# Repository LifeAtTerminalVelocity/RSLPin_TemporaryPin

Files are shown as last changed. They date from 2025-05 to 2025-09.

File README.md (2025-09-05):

# RSLPin TemporaryPin
This project is a Parachute Reserve packing temporary pin, being made out of an RSL Pin

The idea for this project started at the Parachute Industry Association (PIA) Symposium of 2025 held in Daytona Beach, Florida, USA.

A common problem that parachute riggers have is that the temporary pins that they employ to close the reserve pack tray are:
1) Expensive (relative to their expected lifetime).
2) Soft, easy to deform.
3) Deformations turn into nicks or gouges on the pin that damage the reserve closing loop.
4) Have to be replaced frequently.

The idea is to take a straight RSL Pin (Currently being made by CWH in Italy and sold world wide through their regional subsidiaries), encase said pin in a 3d printed plastic form to lend it rigidity and structure, and then having that encased in Type 3 webbing as a means to handle it and track it.

This repository will host the STL files needed to print the pin retention and rigidity plastic. This will also serve as to document the process of edits to this project. Keep in mind that in order to have greater strength and rigidity I have printed these using ASA and 100% infill. I have tried making versions that use lesser infill and they tend to fail after some time in the center stud that carries the load of the pin eye.

The latest STL files:

  v10.x - <a href="https://github.com/LifeAtTerminalVelocity/RSLPin_TemporaryPin/blob/main/STL/RSL_Pin_v10.2_Long.stl">Latest 10.x STL Long</a>

  v10.x - <a href="https://github.com/LifeAtTerminalVelocity/RSLPin_TemporaryPin/blob/main/STL/RSL_Pin_v10.2_Regular.stl">Latest 10.x STL Regular</a>
  
  v10.x - <a href="https://github.com/LifeAtTerminalVelocity/RSLPin_TemporaryPin/blob/main/STL/RSL_Pin_v10.2_Short.stl">Latest 10.x STL Short</a>

  Straight Pin Short v2.1 <a href="https://github.com/LifeAtTerminalVelocity/RSLPin_TemporaryPin/blob/main/STL/StraightPin_v2.1_Short.stl"> Latest Stright Pin 2.x Short STL</a>

The latest 3MF files:
  
  v10.x - <a href="https://github.com/LifeAtTerminalVelocity/RSLPin_TemporaryPin/blob/main/3MF/RSL_Pin_v10.2_Long.3mf">Latest 10.x 3MF Long</a>

  v10.x - <a href="https://github.com/LifeAtTerminalVelocity/RSLPin_TemporaryPin/blob/main/3MF/RSL_Pin_v10.2_Regular.3mf">Latest 10.x 3MF Regular</a>

  v10.x - <a href="https://github.com/LifeAtTerminalVelocity/RSLPin_TemporaryPin/blob/main/3MF/RSL_Pin_v10.2_Short.3mf">Latest 10.x 3MF Short</a>

The history of the project can be read here - <a href="https://github.com/LifeAtTerminalVelocity/RSLPin_TemporaryPin/blob/main/History.md"> History.md </a>

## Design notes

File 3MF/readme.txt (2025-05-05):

These are 3MF files. I have a Bambu printer and the Bambu Studio default file type is 3MF.

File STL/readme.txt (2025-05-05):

These are STL files. If you are new to 3d printing this is the kind of file you need to add into your slicer to then generate a print.

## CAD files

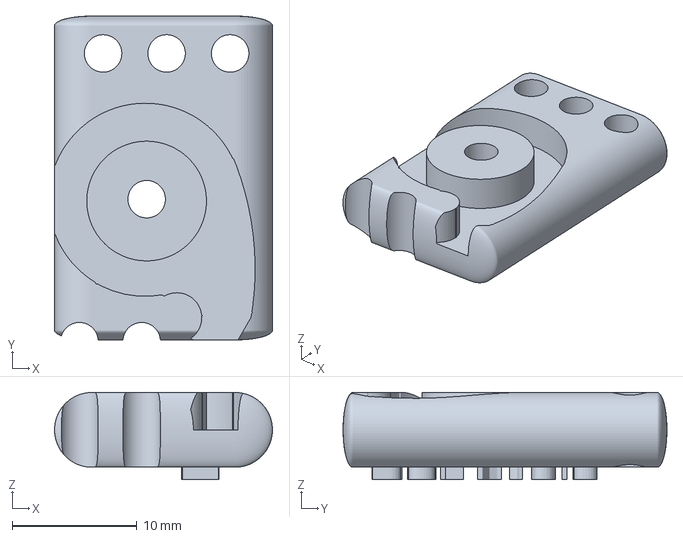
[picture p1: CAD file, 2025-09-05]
3MF/RSL_Pin_v10.2_Short.3mf
17.5 x 26.0 x 6.99 mm

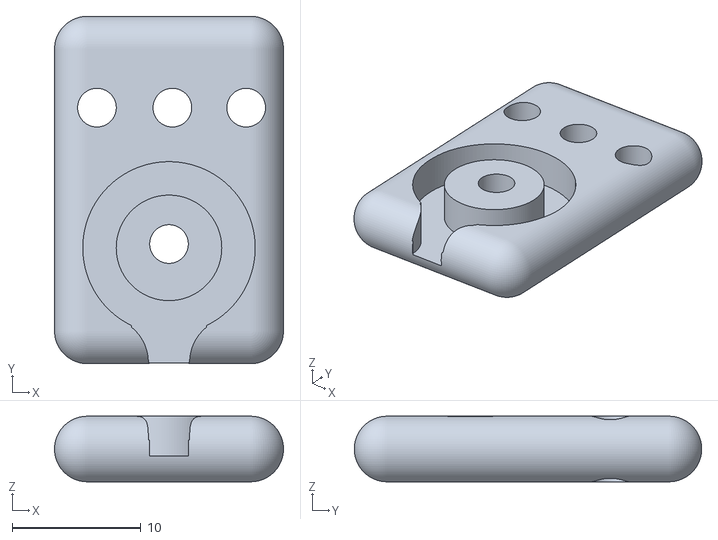
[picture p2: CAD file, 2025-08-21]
STL/StraightPin_v2.1_Short.stl
17.8 x 27.0 x 5.10

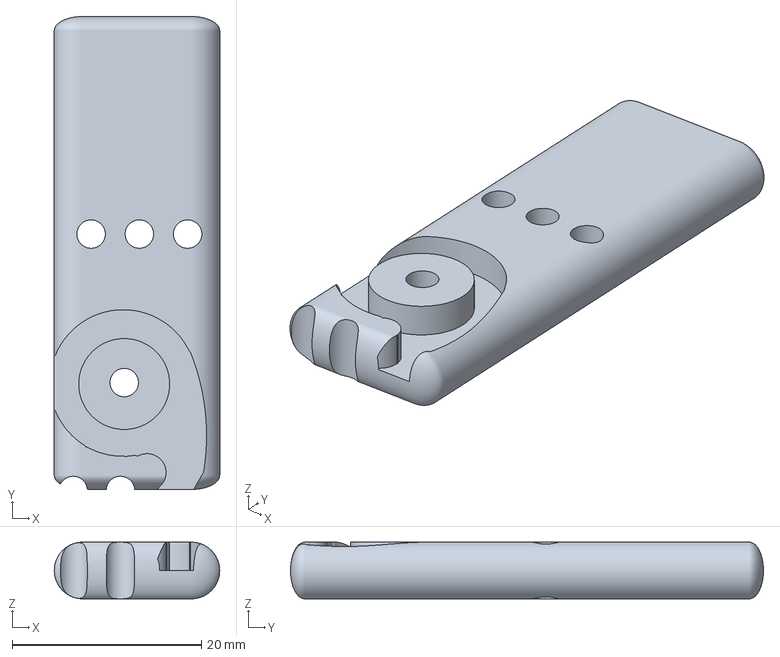
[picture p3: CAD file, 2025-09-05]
3MF/RSL_Pin_v10.2_Regular.3mf
17.5 x 50.0 x 6.00 mm

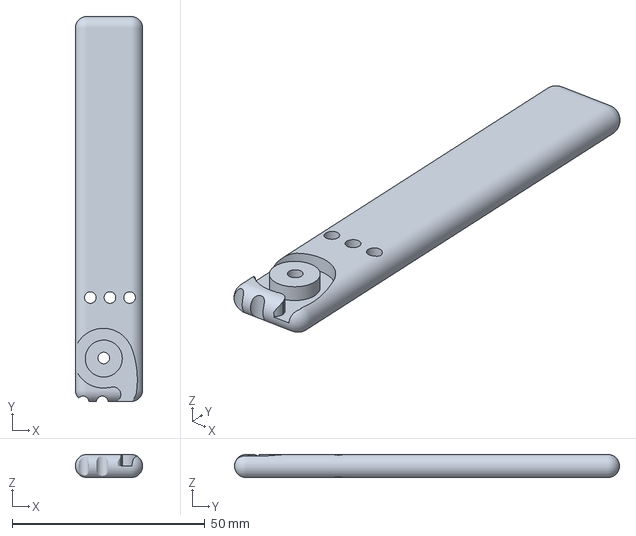
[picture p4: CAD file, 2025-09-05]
3MF/RSL_Pin_v10.2_Long.3mf
17.5 x 100.0 x 6.00 mm

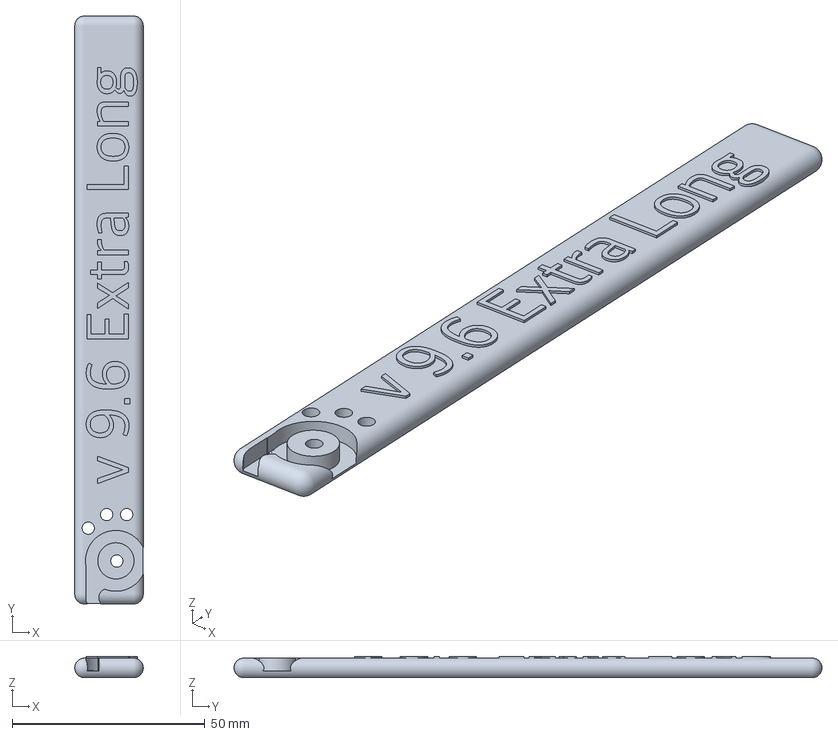
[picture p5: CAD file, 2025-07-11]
3MF/RSL Pin Holder - v9.6 ExtraLong.3mf
17.8 x 152.4 x 5.54 mm

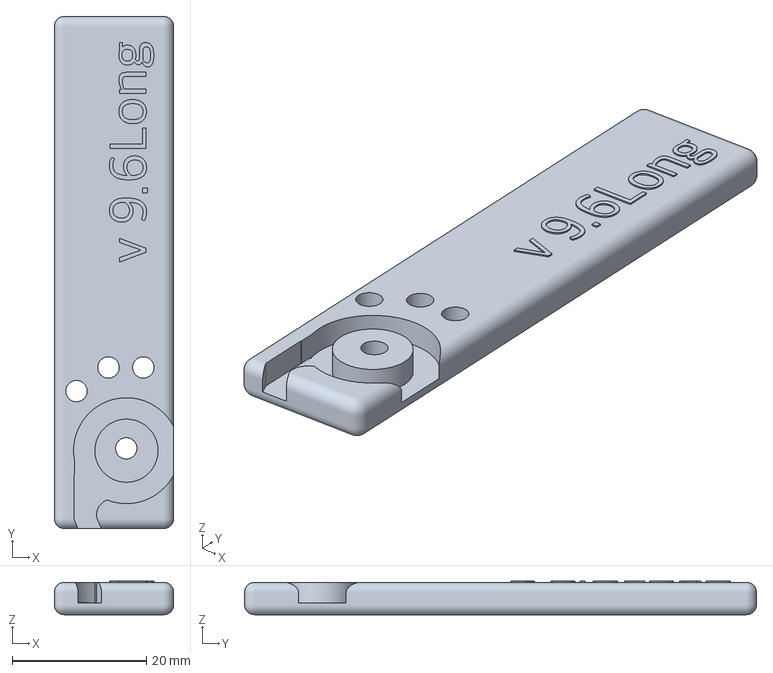
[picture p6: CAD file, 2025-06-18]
3MF/RSL Pin Holder - v9.6 Long.3mf
17.8 x 76.2 x 4.99 mm

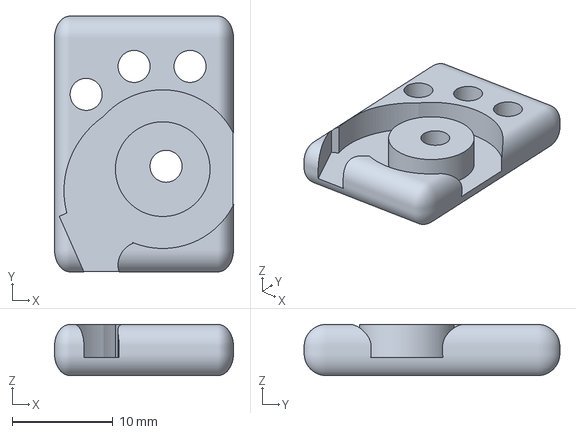
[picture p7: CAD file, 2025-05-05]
3MF/RSL Pin Holder - v9.5.3mf
17.8 x 25.4 x 5.08 mm

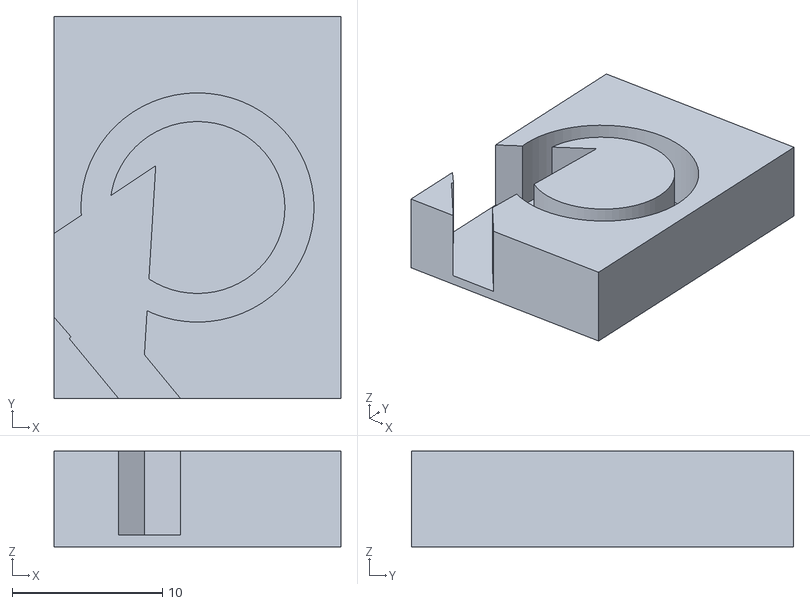
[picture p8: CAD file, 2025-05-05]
STL/RSL Pin Holder.stl
19.1 x 25.4 x 6.35

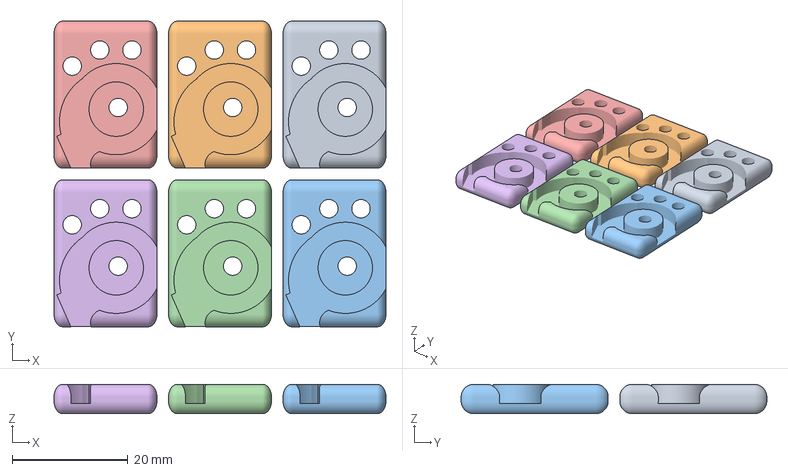
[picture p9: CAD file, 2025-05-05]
3MF/RSL Pin Holder - v9.1mf.3mf
57.3 x 52.8 x 5.08 mm
RSL Pin Holder - v9.1.stl x 6

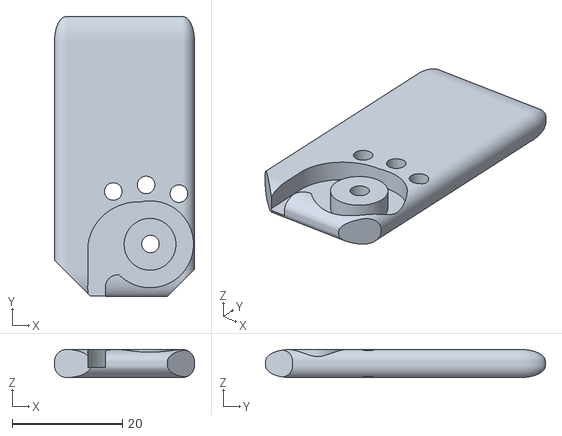
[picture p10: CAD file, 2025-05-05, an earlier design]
STL/RSL Pin Holder - v7.1.stl
25.4 x 50.8 x 5.08

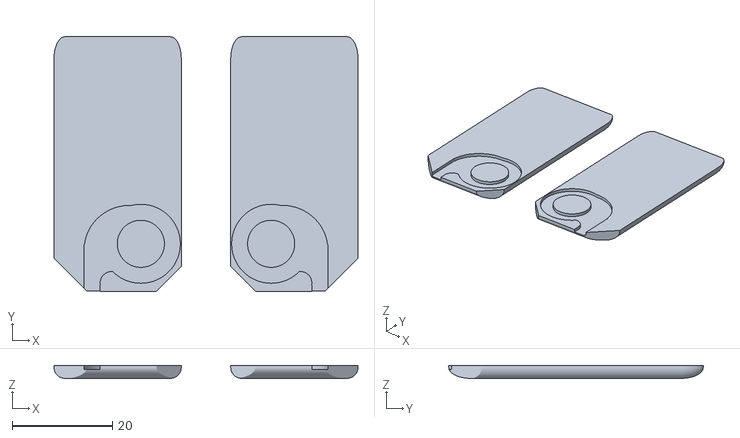
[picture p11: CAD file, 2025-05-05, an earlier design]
STL/RSL Pin Holder - v8.stl
60.7 x 50.8 x 2.54

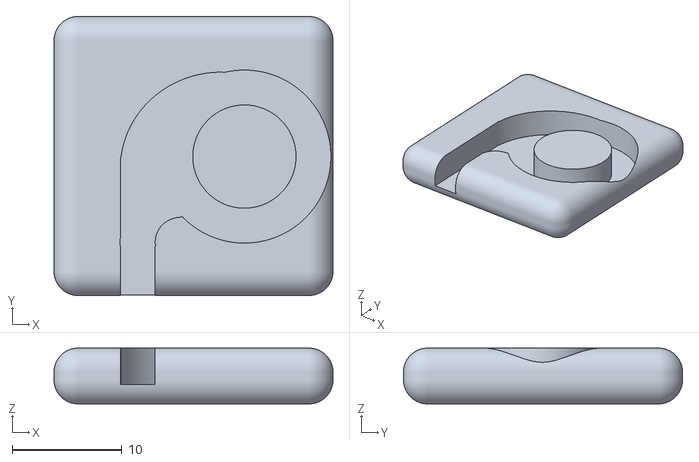
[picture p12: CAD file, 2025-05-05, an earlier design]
STL/RSL Pin Holder - v6.3.stl
25.4 x 25.4 x 5.08

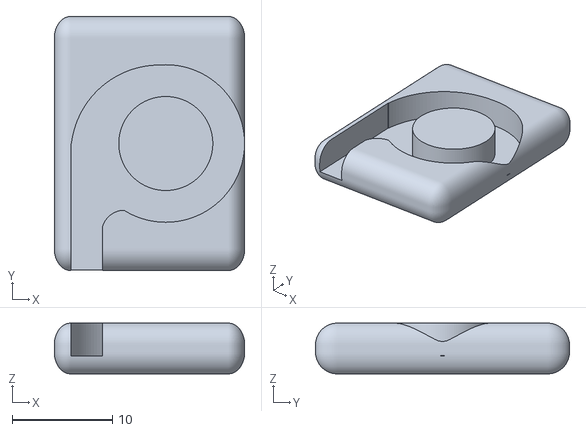
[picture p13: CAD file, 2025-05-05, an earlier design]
STL/RSL Pin Holder - v6.stl
19.0 x 25.4 x 5.08

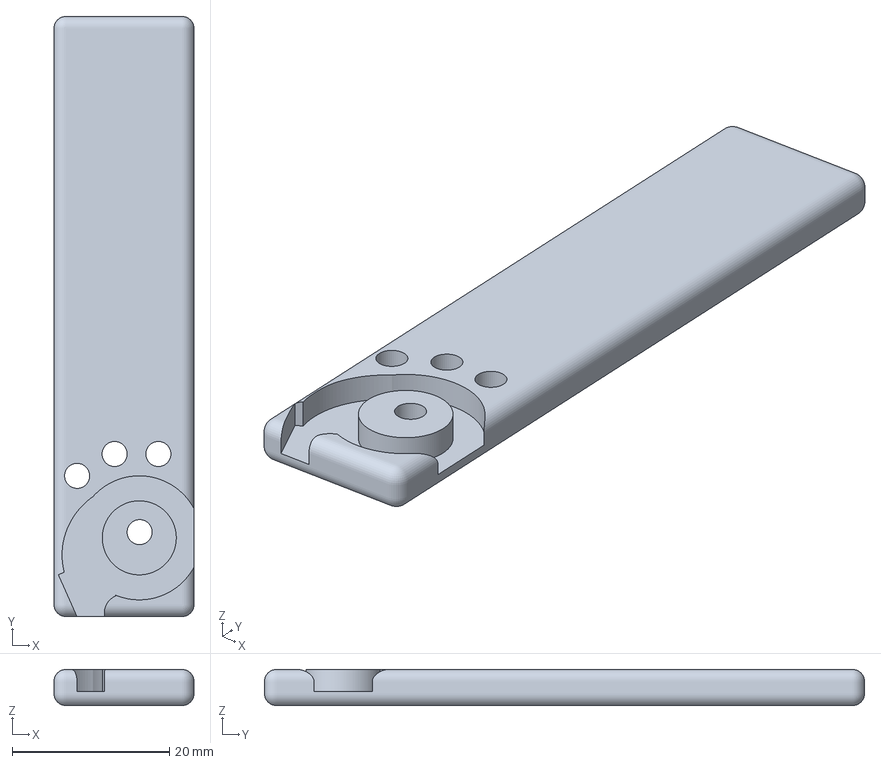
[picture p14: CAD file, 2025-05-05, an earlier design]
3MF/RSL Pin Holder - v7.5 Long.3mf
17.8 x 76.2 x 4.57 mm

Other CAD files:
STL/RSL Pin Holder - v9.1.stl
3MF/RSL Pin Holder - v7.3mf
STL/RSL Pin Holder v5.stl
STL/RSL Pin Holder v4.stl
STL/RSL Pin Holder - v6.1.stl
STL/RSL Pin Holder - v6.2.stl
STL/RSL Pin Holder - v7.2.stl
STL/RSL Pin Holder - v7.4 Long.stl
STL/RSL Pin Holder - v7.5 Long.stl
STL/RSL Pin Holder - v7.stl
STL/RSL Pin Holder - v8.1.stl
STL/RSL Pin Holder - v9.0.stl
STL/RSL Pin Holder - v9.4.stl
STL/RSL Pin Holder - v9.6 ExtraLong.stl
STL/RSL Pin Holder - v9.6 Long.stl
STL/RSL Pin Holder v2.stl
STL/RSL Pin Holder v3.stl
STL/RSL_Pin_v10.2_Long.stl
STL/RSL_Pin_v10.2_Regular.stl
STL/RSL_Pin_v10.2_Short.stl

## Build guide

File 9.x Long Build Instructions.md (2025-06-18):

# Build Instructions for v9.x

You can follow these instructions to build yourself a version 9.x Temporary pin.

1) Cut 30" (76cm) of your favorite colored Type 3 or Type 4 webbing.

2) Fold back 6" (15cm).
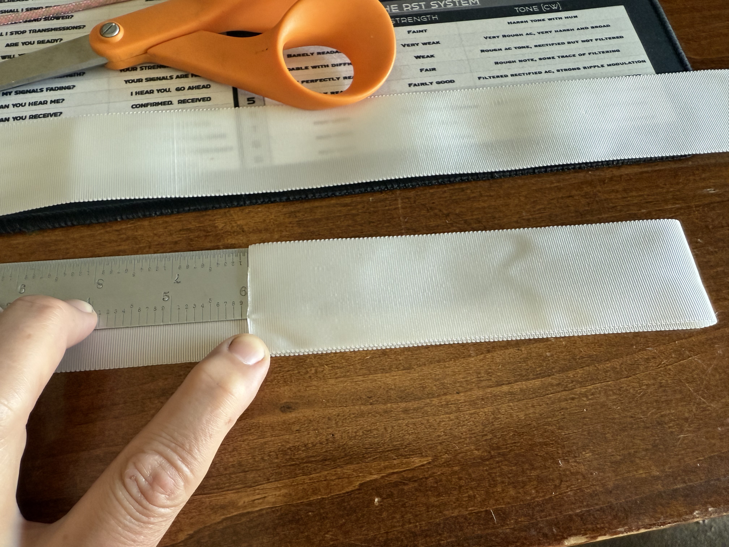
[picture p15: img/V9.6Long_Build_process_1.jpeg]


3) Use the printed holder as a guide and mark your webbing for: Width, length, and exit point of the RSL Pin. I like to mark my webbing with 1/16th" (1.5mm) gap on either side.
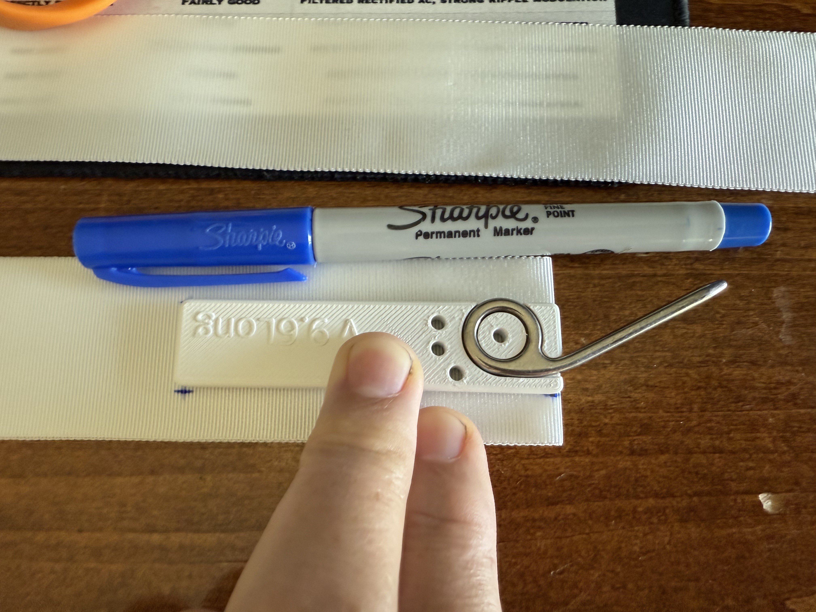
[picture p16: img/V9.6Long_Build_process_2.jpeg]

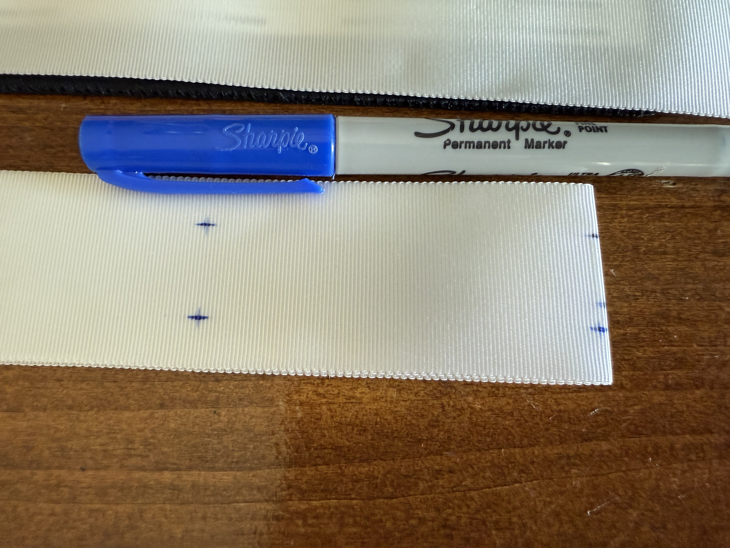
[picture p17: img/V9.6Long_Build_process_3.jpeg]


4) Run a straight stitch line from the fold over edge to the length of the RSL Pin Holder.
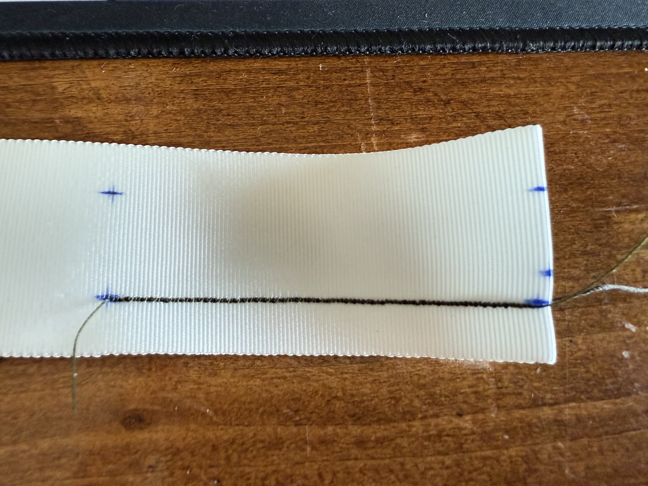
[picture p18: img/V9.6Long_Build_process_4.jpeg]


5) Run a second straight stitch line from the fold over edge to the length of the RSP Pin Holder on the opposite side. This will make the tunnel where the RSL Pin Holder will be inserted into.
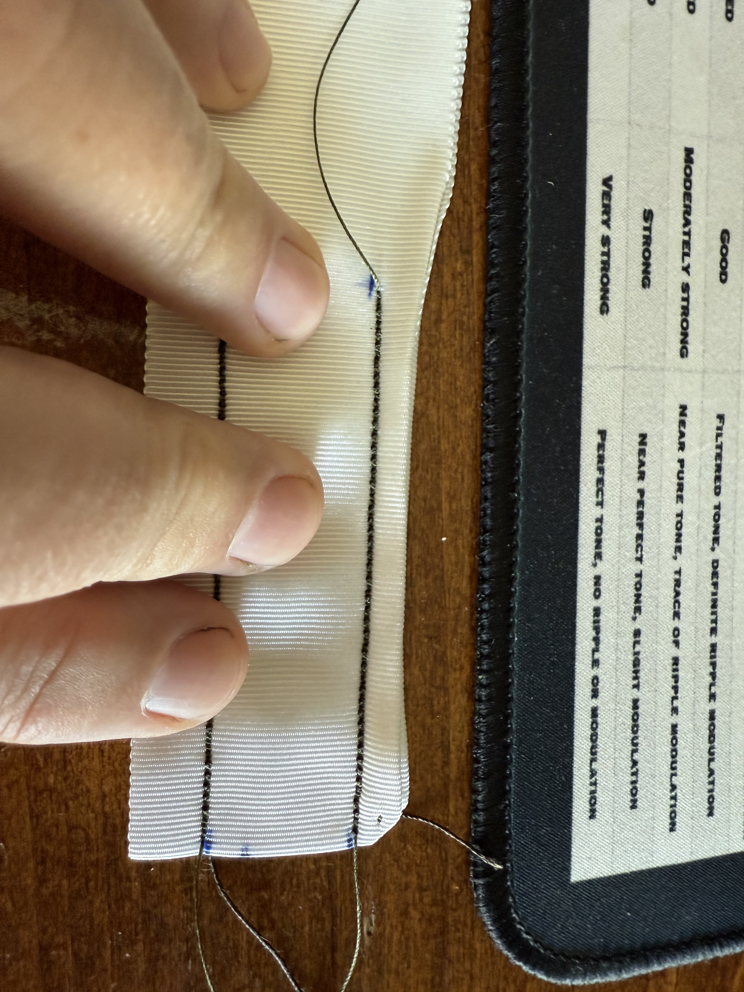
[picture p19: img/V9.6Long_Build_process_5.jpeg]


6) Your webbing should look something like this now:


7) Seat the RSL Pin into the RSL Pin Holder. This will be a *snug* fit.

8) (Optional)Using some Supertack line secure the pin to the RSL Pin Holder. There are 3 holes around the perimeter, and one on the center. I line up my tack so that I can slip the knot into the center hole within the pin retention mechanism. Use all 3 perimeter holes to form a retention line against the pin.
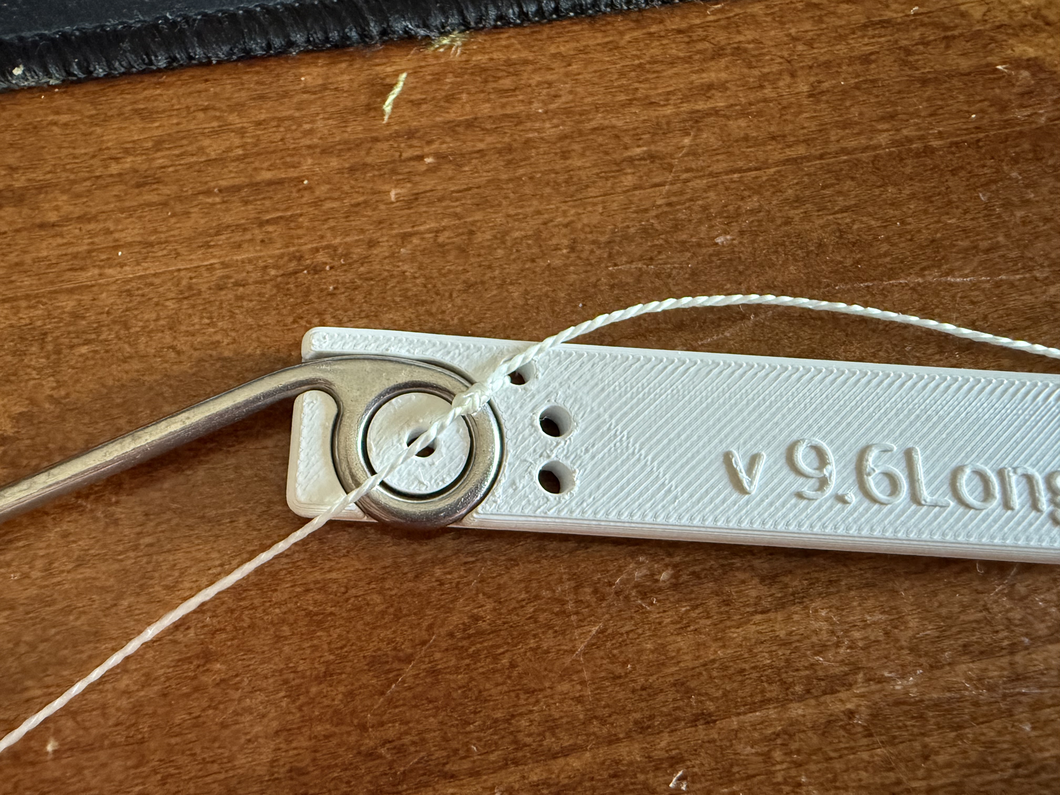
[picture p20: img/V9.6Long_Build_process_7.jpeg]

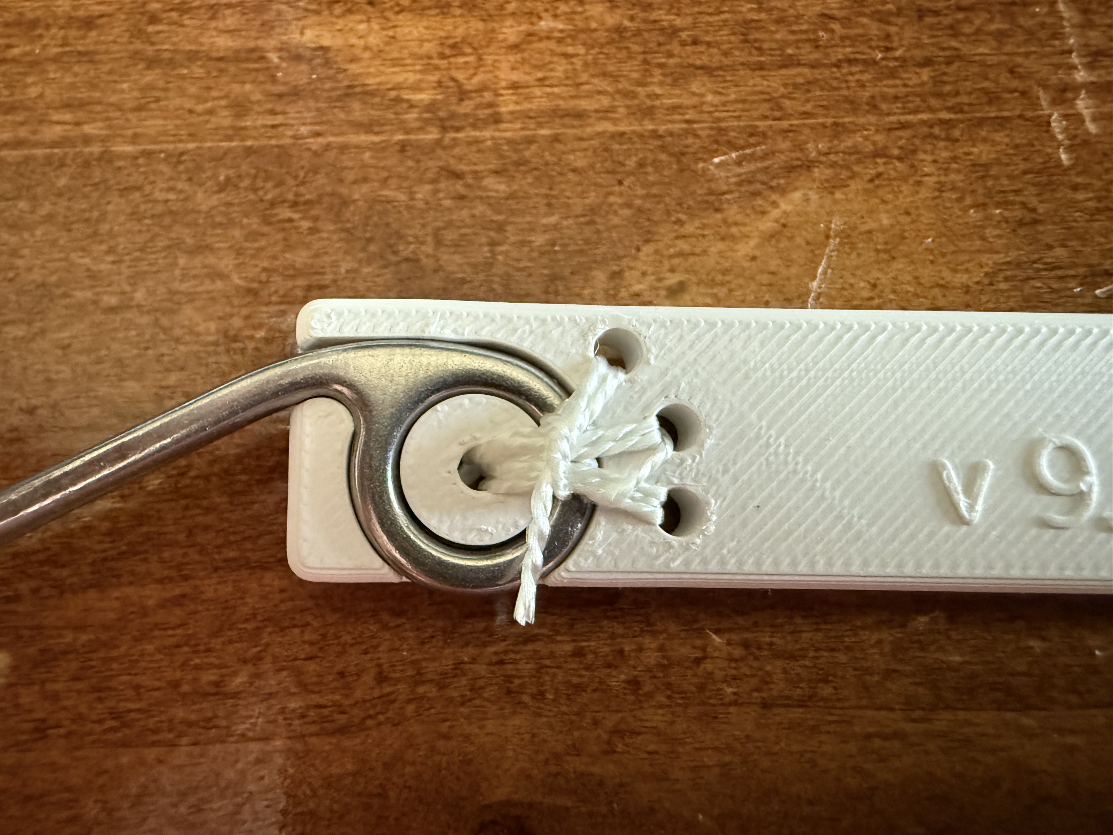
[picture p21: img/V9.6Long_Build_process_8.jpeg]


9) Insert the RSL Pin & RSL Pin Holder into the tunnel made in the webbing. Keep in mind that this will also be a snug fit and that you will have to scrunch the material so that you can line up the RSL Pin Tip with the mark you made for where it should exit on the webbing.
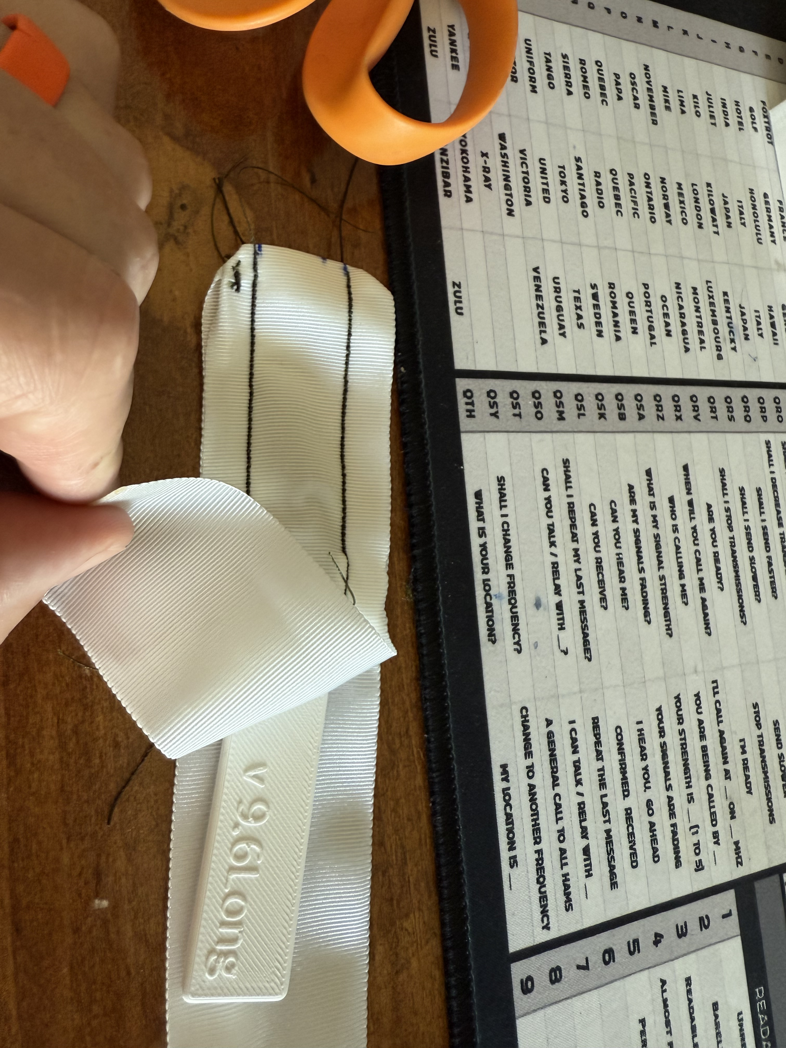
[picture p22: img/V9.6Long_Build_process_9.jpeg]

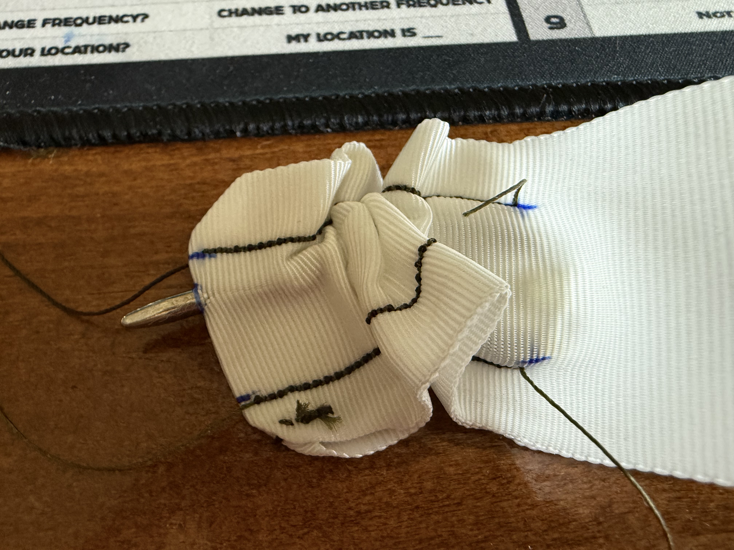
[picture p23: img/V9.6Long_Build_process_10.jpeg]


10) Your assembly should look like this now.
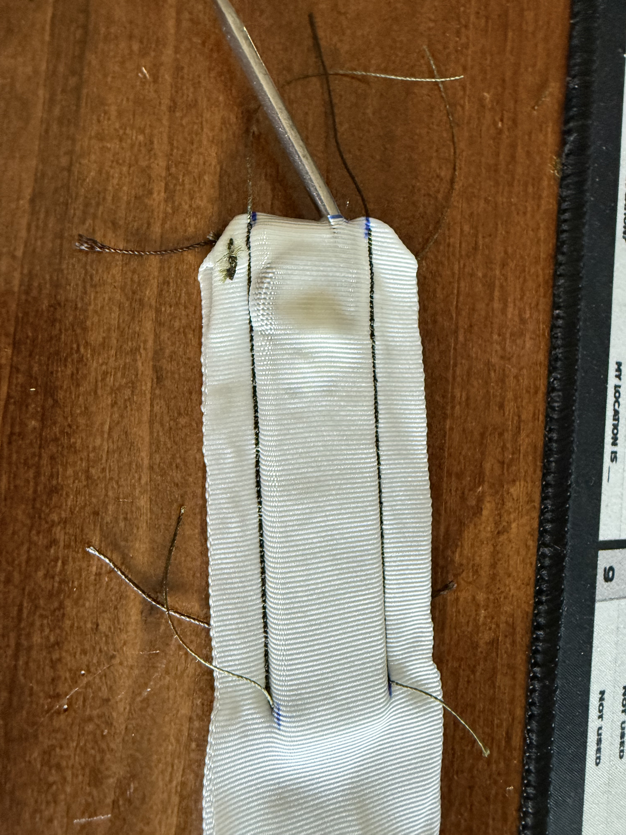
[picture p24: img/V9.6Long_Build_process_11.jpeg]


11) Run a stitch line behind the end of the RSL Pin holder as close as you can get with the foot of the sewing machine down.
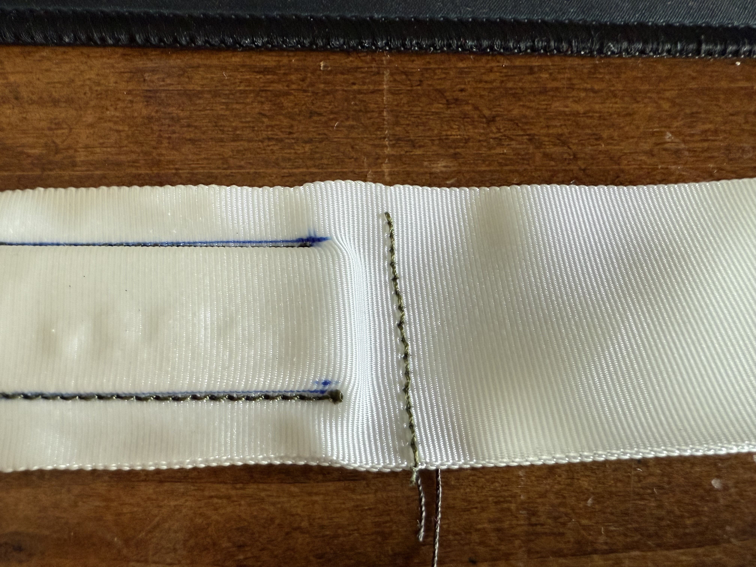
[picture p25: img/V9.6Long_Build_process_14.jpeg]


12) Run another stitch as close as you can get to the RSL Pin Holder with the sewing machine foot up. 
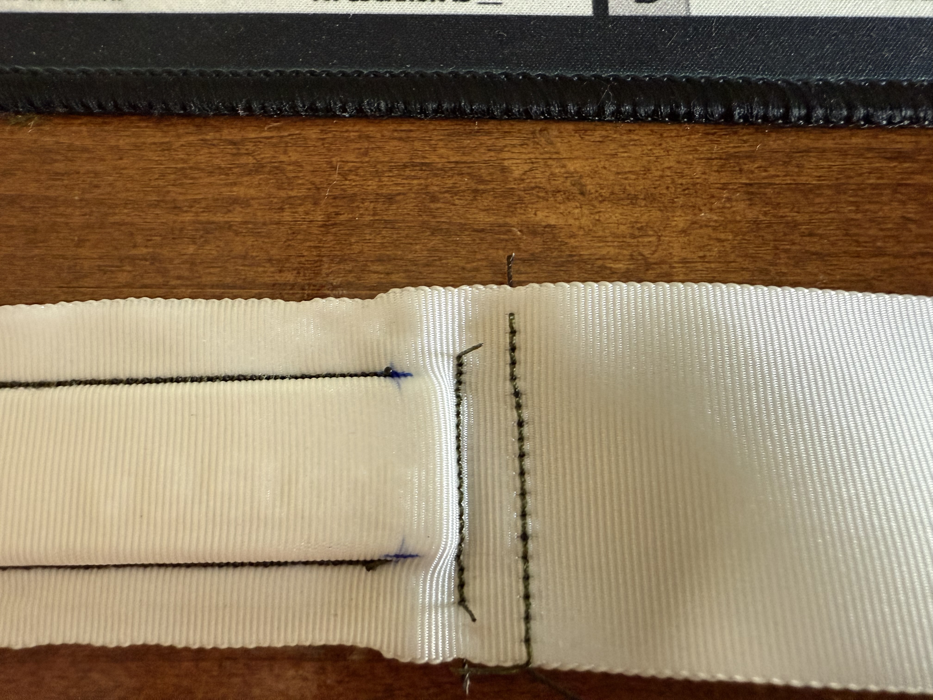
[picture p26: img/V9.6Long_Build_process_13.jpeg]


13) Fold over the remaining webbing from the 1st fold over back under itself so that it butts up to the stitch line.
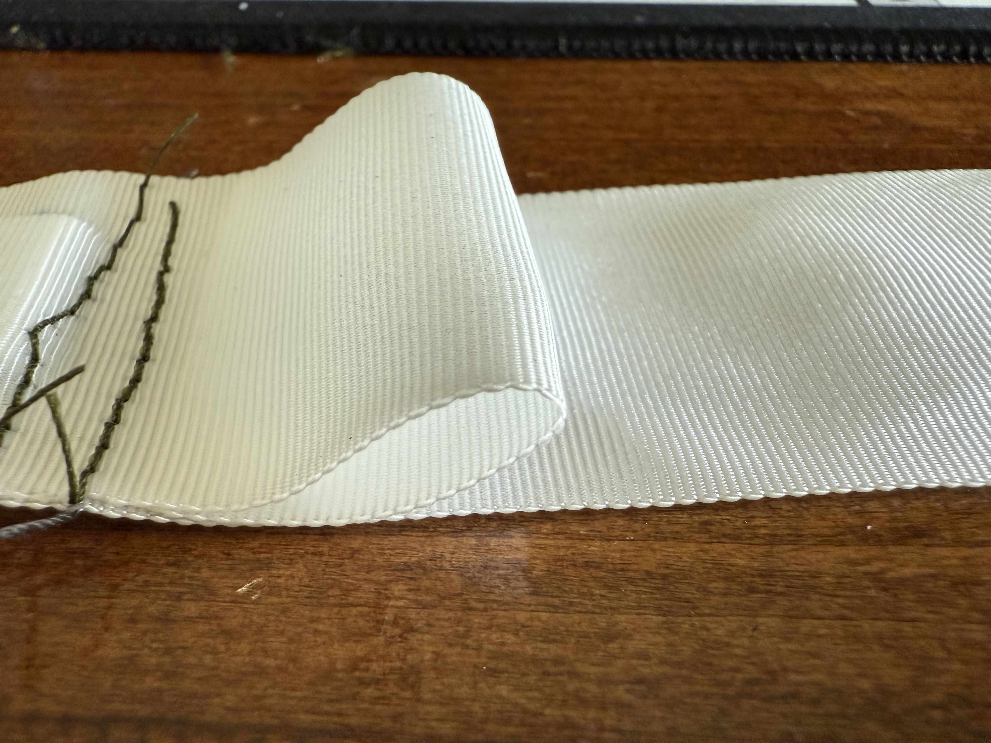
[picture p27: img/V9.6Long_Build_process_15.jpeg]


14) Run a zigzag stitch along the length of fold over edge. The idea here is to remove any snag points on your temp pin lanyard. The ones I build have a zigzag stitch going and another one coming.
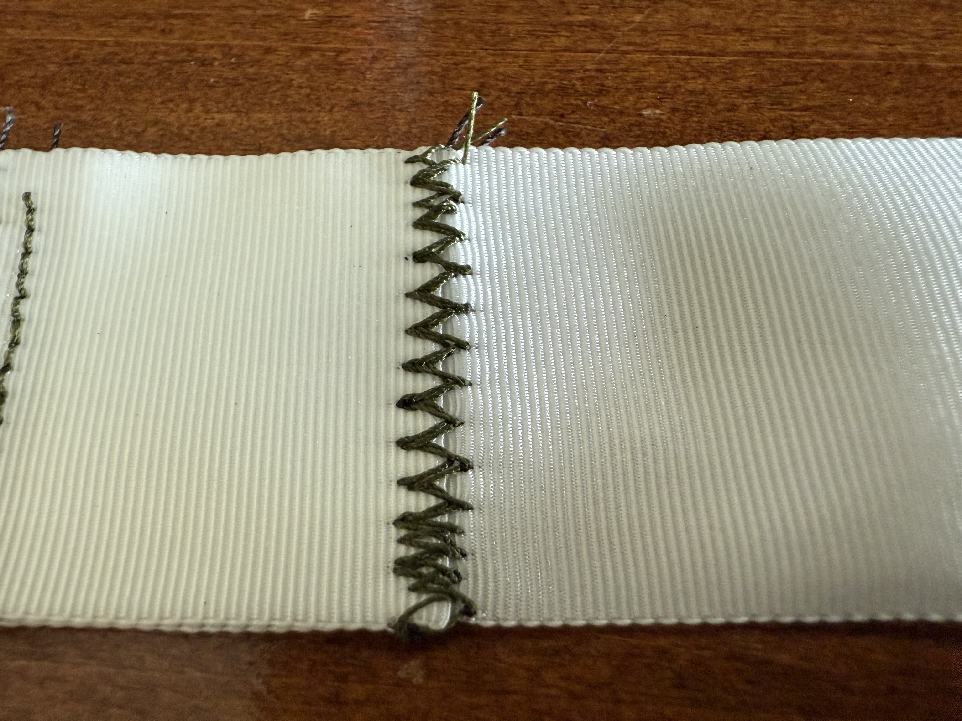
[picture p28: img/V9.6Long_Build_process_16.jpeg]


15) Your completed pin should look like this.
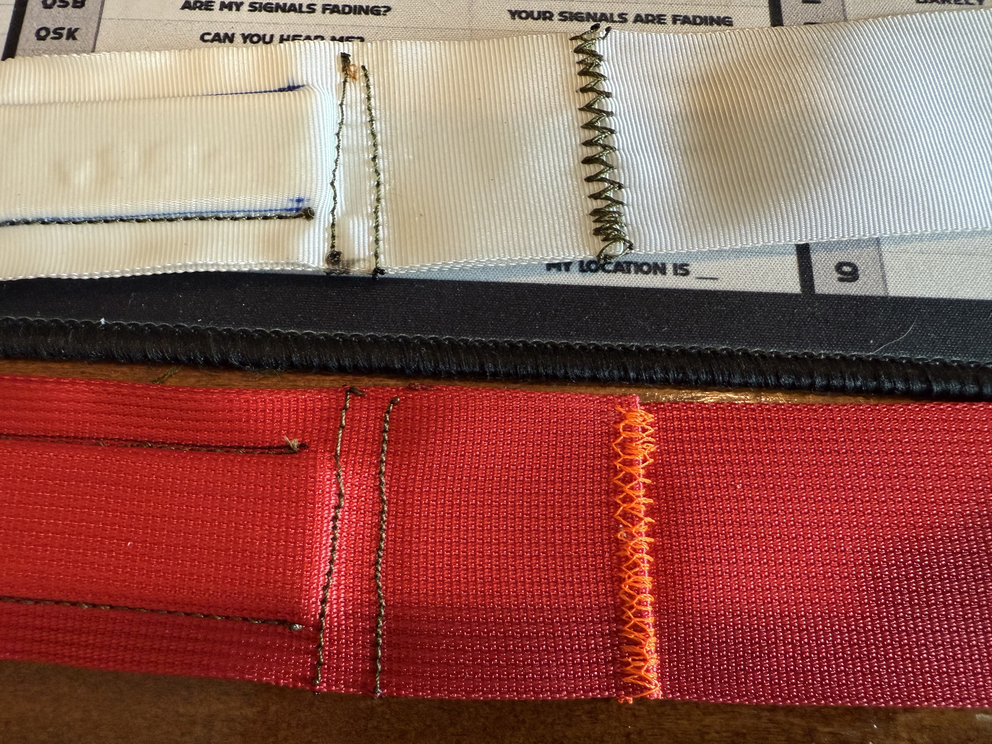
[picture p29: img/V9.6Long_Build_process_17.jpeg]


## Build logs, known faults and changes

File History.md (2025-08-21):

# RSLPin TemporaryPin
This project is a Parachute Reserve packing temporary pin, being made out of an RSL Pin

The idea for this project started at the Parachute Industry Association (PIA) Symposium of 2025 held in Daytona Beach, Florida, USA.

A common problem that parachute riggers have is that the temporary pins that they employ to close the reserve pack tray are:
1) Expensive (relative to their expected lifetime).
2) Soft, easy to deform.
3) Deformations turn into nicks or gouges on the pin that damage the reserve closing loop.
4) Have to be replaced frequently.

The idea is to take a straight RSL Pin (Currently being made by CWH in Italy and sold world wide through their regional subsidiaries), encase said pin in a 3d printed plastic form to lend it rigidity and structure, and then having that encased in Type 3 webbing as a means to handle it and track it.

This repository will host the STL files needed to print the pin retention and rigidity plastic. This will also serve as to document the process of edits to this project. Keep in mind that in order to have greater strength and rigidity I have printed these using ASA and 100% infill. I have tried making versions that use lesser infill and they tend to fail after some time in the center stud that carries the load of the pin eye.

The latest STL files:
  
  v7.x - <a href="https://github.com/LifeAtTerminalVelocity/RSLPin_TemporaryPin/blob/main/STL/RSL%20Pin%20Holder%20-%20v7.5%20Long.stl">Latest 7.x STL</a>
  
  v9.x - <a href="https://github.com/LifeAtTerminalVelocity/RSLPin_TemporaryPin/blob/main/STL/RSL%20Pin%20Holder%20-%20v9.6%20Long.stl)">Latest 9.x STL</a>

  Straight Pin Short v2.1 <a href="https://github.com/LifeAtTerminalVelocity/RSLPin_TemporaryPin/blob/main/STL/StraightPin_v2.1_Short.stl"> Latest Stright Pin 2.x Short STL</a>

The latest 3MF files:
  
  v7.x - <a href="https://github.com/LifeAtTerminalVelocity/RSLPin_TemporaryPin/blob/main/3MF/RSL%20Pin%20Holder%20-%20v7.5%20Long.3mf">Latest 7.x 3MF</a>
  
  v9.x - <a href="https://github.com/LifeAtTerminalVelocity/RSLPin_TemporaryPin/blob/main/3MF/RSL%20Pin%20Holder%20-%20v9.6%20Long.3mf">Latest 9.x 3MF</a>

Versions 1-5:

These are poorly revision managed initial itterations to fit the pin into the plastic holder. This version is meant to be used with 1" (2.54cm) Type 4 webbing. 

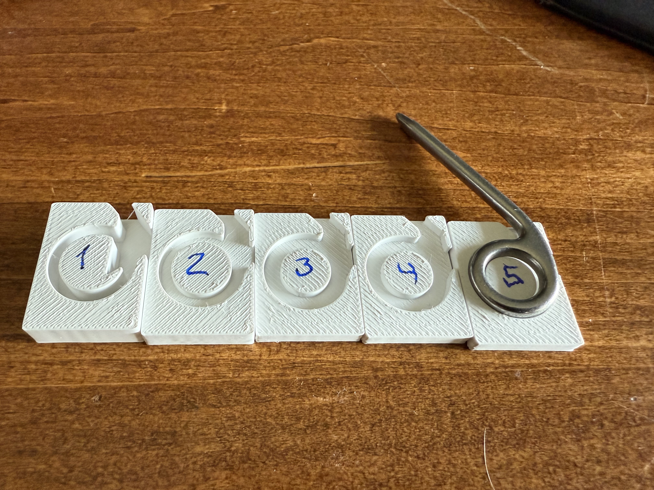
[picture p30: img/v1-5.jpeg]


Version 6:

This is the first iteration of the pin holder that fits well. The initial 3 prototypes were made with this version. This version is meant to be used with 1" (2.54cm) Type 4 webbing.

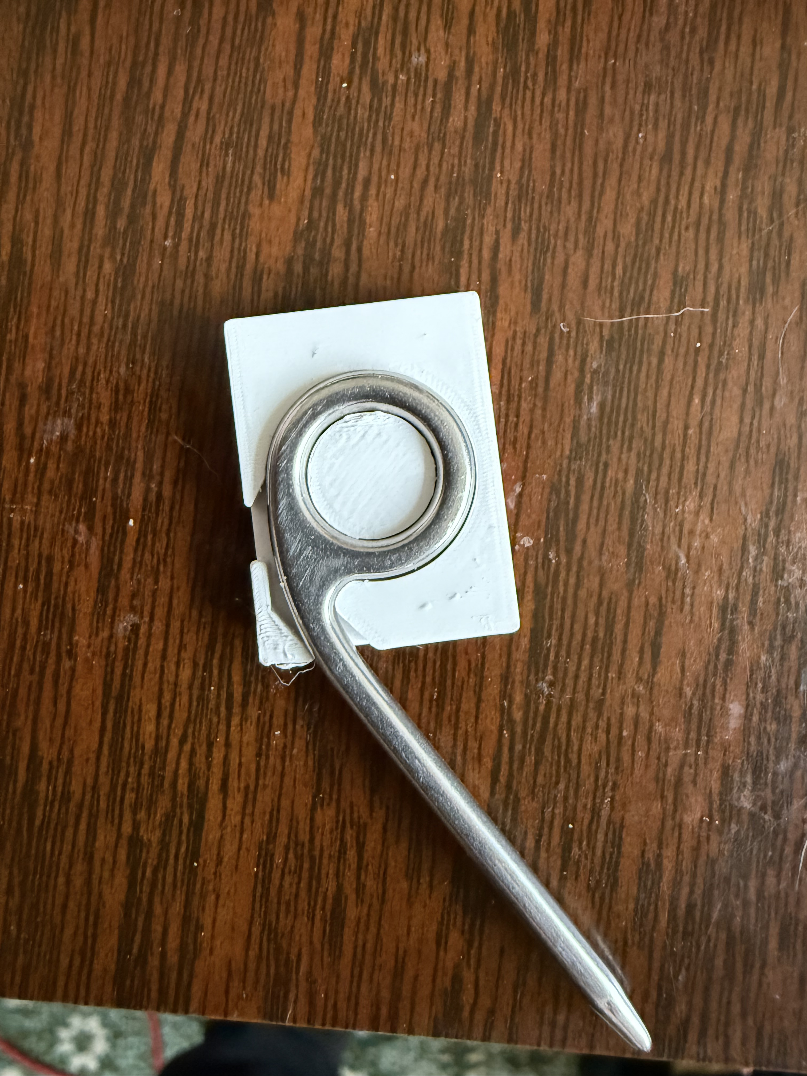
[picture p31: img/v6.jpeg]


Version 6.1:
Similar to version 6 but this version is meant to be used with 1.5" (3.81cm) Type 4 webbing.

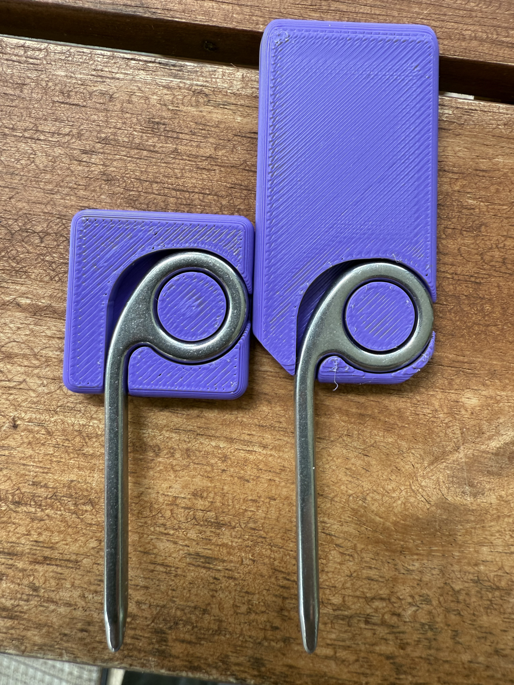
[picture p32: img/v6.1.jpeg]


Version 6.2:
A revision of v 6.1 incorporating feedback from the riggers that tested v6 and v6.1. It features cut off corners.

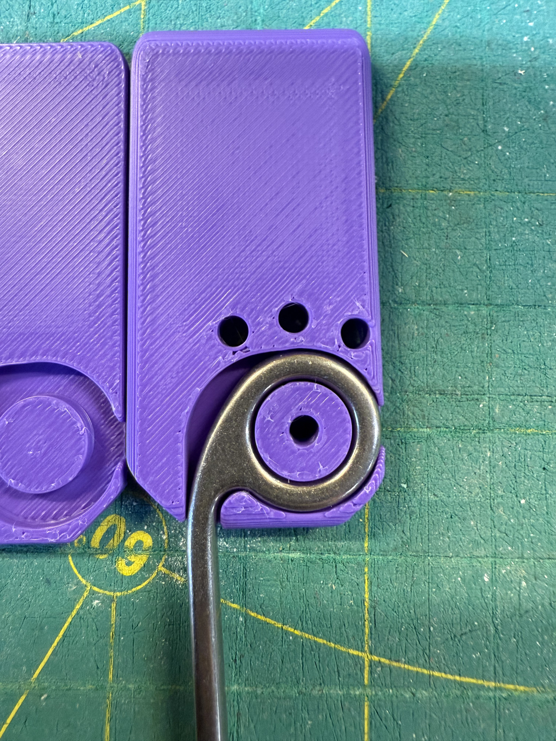
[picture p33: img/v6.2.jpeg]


Version 6.3
A revision of v 6.2 incorporating feedback from the riggers that tested v6.2. It features thru holes for tacking down the pin.

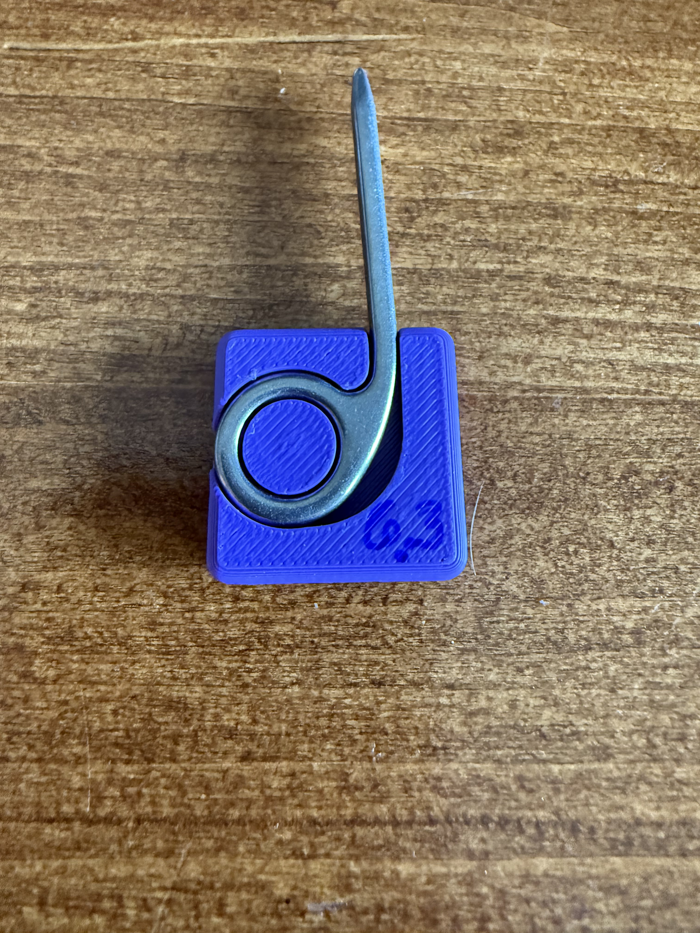
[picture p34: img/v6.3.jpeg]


Version 7.x:
A revision of v6.2 with a longer length (3" or 7.6cm) to allow for better handling of the pin. Going forward this version will be the "Long" version of the RSL Pin Holder. Revisions within it will be documented under this block.

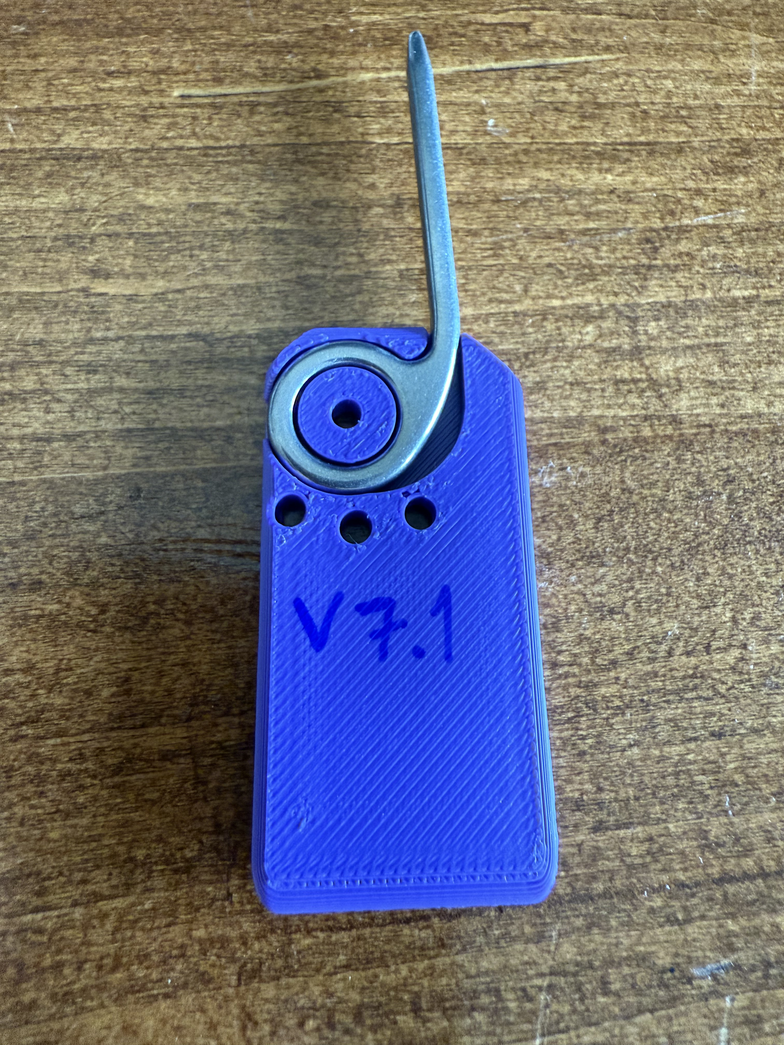
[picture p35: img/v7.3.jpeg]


Version 8.x:
Attemps to make the RSL Pin Holder a clamshell design. This fails misserably. I might try this again in the future with a different approach to the clamshell but right now the focus will be v7.x and v9.x

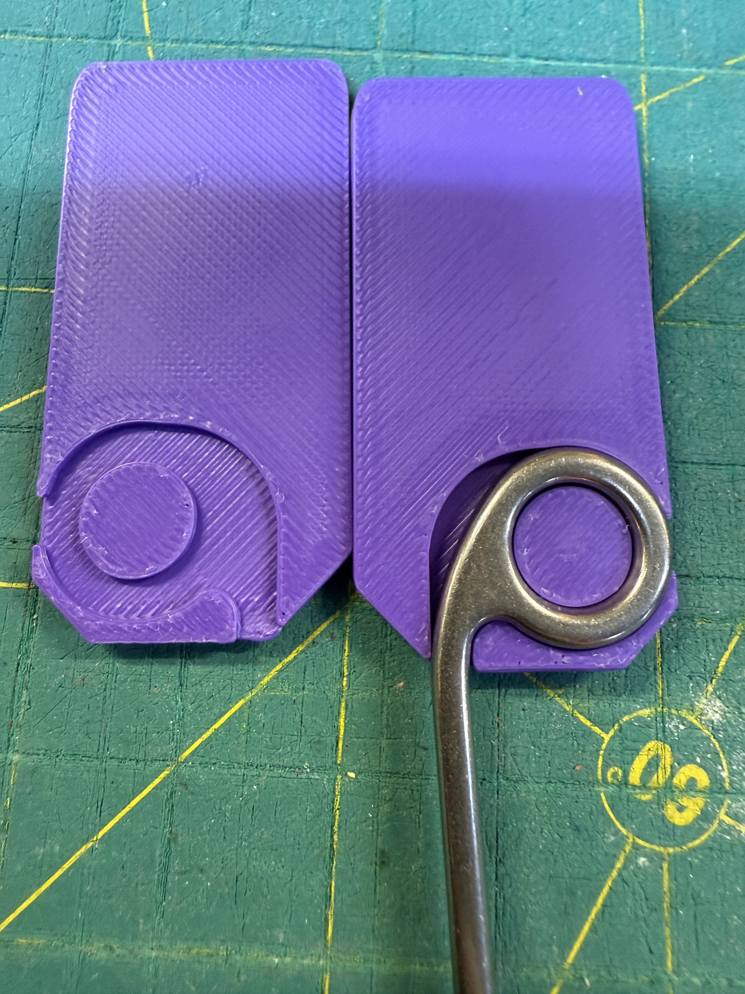
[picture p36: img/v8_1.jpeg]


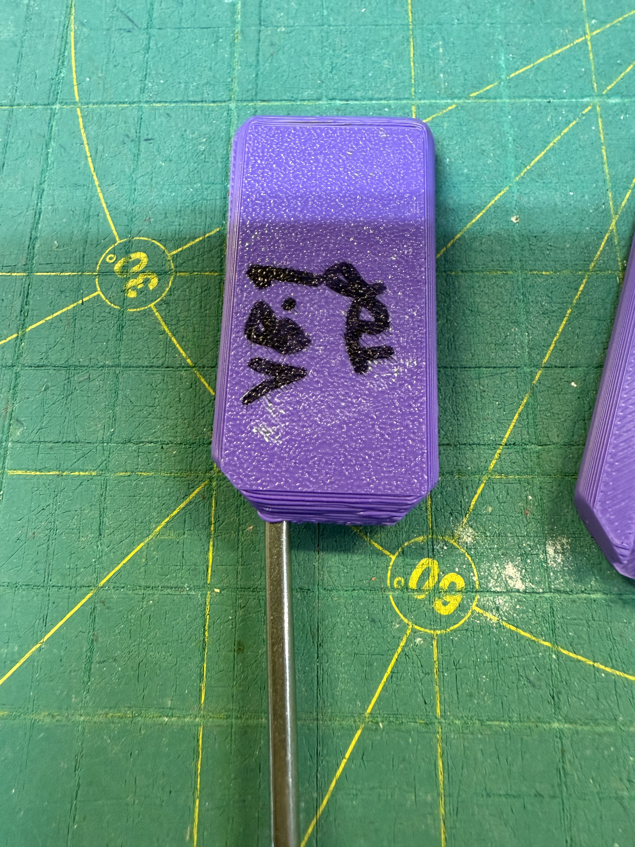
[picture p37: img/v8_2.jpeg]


Version 9.x:
Together with v7.x this will be the standard length (1" or 2.54cm) version of the RSL Pin Holder. Going forward this version will be the "Long" version of the RSL Pin Holder. Revisions within it will be documented under this block.

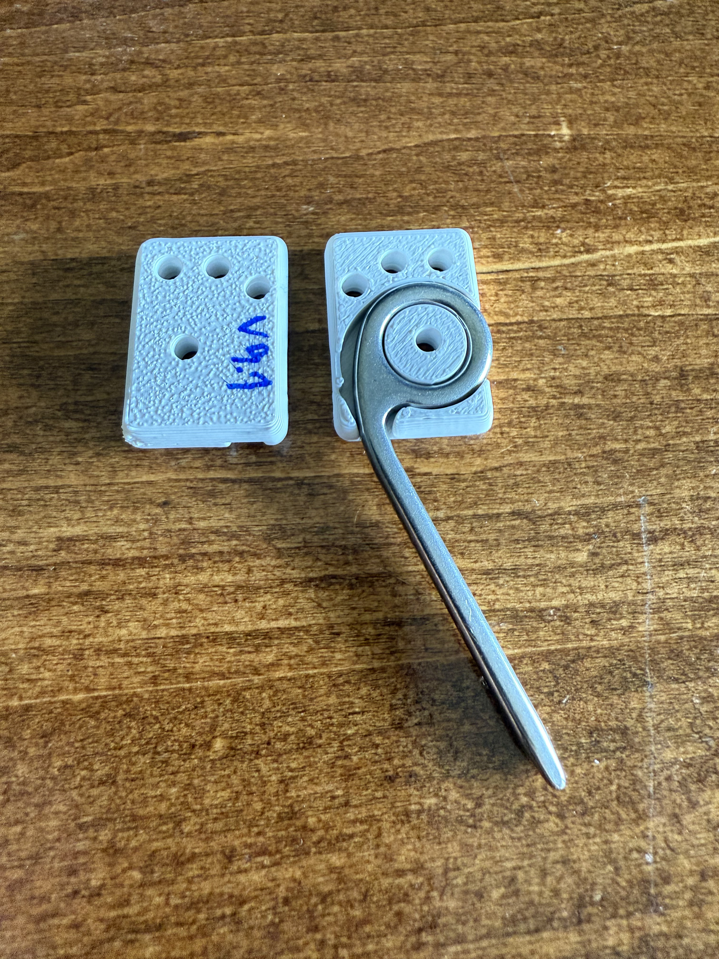
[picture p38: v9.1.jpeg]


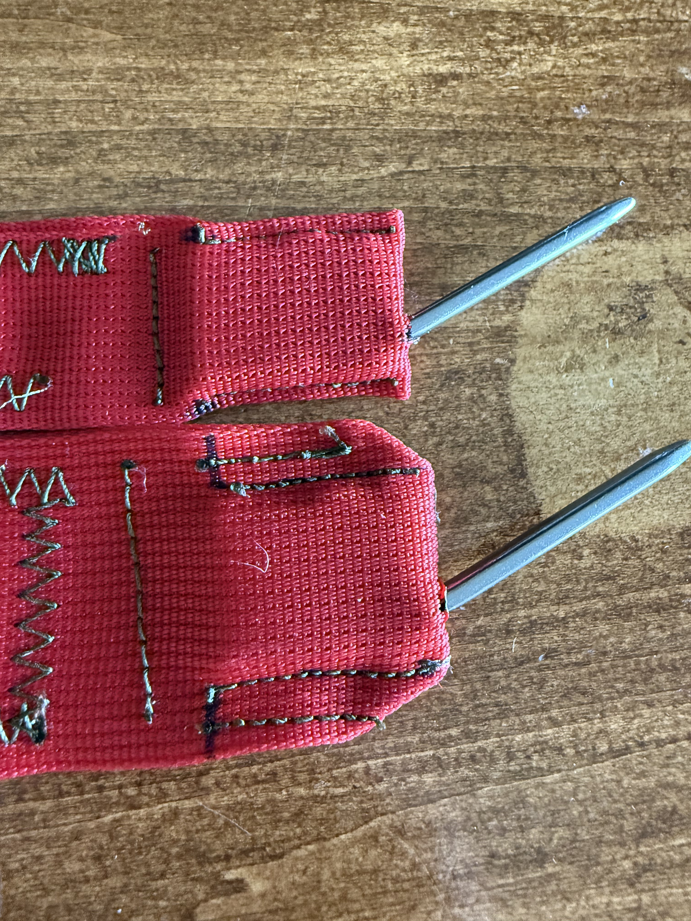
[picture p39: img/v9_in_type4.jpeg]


Acknowledgements:

Thanks to the riggers that are testing the prototypes of these TemporaryReserve Pins. Your feedback and assistance means a lot to me.

Andi Paulsen

Sergio Revuelta

Madisen Boyer

Hunter Amundson.

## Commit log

2025-06-18 Add files via upload
    Version 9.6 Long - better pin retention geometry.
    [RSL Pin Holder - v9.6 Long.3mf]
2025-06-18 Add files via upload
    Version 9.6 Long
    [RSL Pin Holder - v9.6 Long.stl]
2025-07-11 A special version of the 9.6 pin for Tracy
    A special version of the 9.6 pin holder to see if it helps Tracy with closing reserves given his flailing dexterity on his primary hand.
    [RSL Pin Holder - v9.6 ExtraLong.3mf]
2025-09-05 2025-09-05 Long version of the RSL Pin Holder
    Added some notches to the bottom of the pin holder edge to act as a place to anchor Tacking. The sample I provided to Maddy became dislodged when torqued and she suggested adding a way to tack the bottom of the pin as a way to prevent the issue.
    [RSL_Pin_v10.2_Long.stl]
2025-09-05 2025-09-05 Long version of the RSL Pin Holder
    Added some notches to the bottom of the pin holder edge to act as a place to anchor Tacking. The sample I provided to Maddy became dislodged when torqued and she suggested adding a way to tack the bottom of the pin as a way to prevent the issue. In addition the text identifying the piece is now embossed to prevent wear on the Type III webbing as it is used.
    [RSL_Pin_v10.2_Long.3mf]
2025-09-05 2025-09-05 Short version of the RSL Pin Holder
    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
    [RSL_Pin_v10.2_Short.stl]
